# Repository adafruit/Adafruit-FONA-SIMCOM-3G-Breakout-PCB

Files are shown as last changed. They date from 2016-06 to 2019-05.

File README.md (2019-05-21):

## Adafruit FONA SIMCOM 3G Breakouts PCB
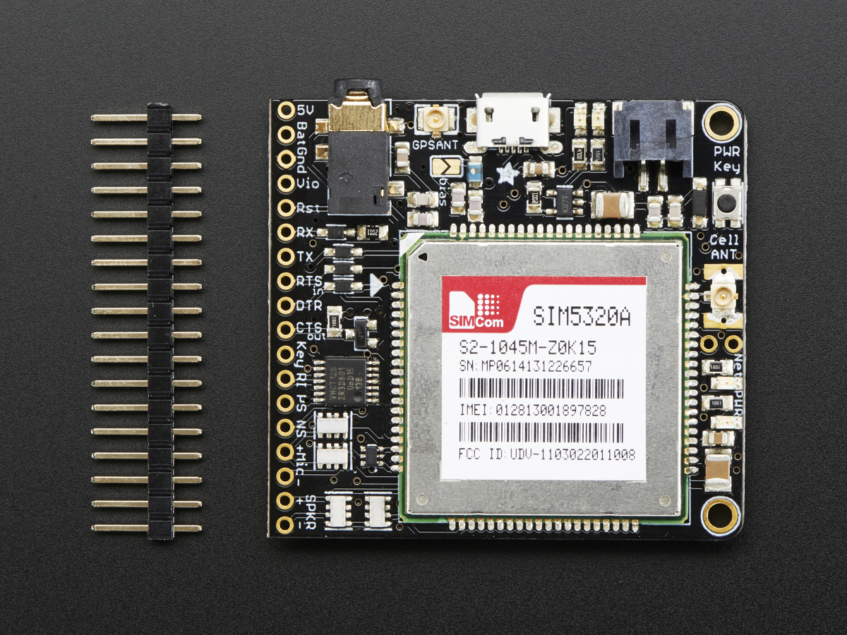
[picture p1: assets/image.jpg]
<a href="http://www.adafruit.com/products/3147"><br/>
Click here to purchase one from the Adafruit shop</a>

For those who want to take it to the next level we now have a 3G Cellular Modem breakout! The FONA 3G has better coverage, GSM backwards-compatibility and even sports a built-in GPS module for geolocation & asset tracking. This all-in-one cellular phone module with that lets you add location-tracking, voice, text, SMS and data to your project in a single breakout.

This module measure only 1.75"x1.6" but packs a surprising amount of technology into it's little frame. At the heart is a powerfull GSM cellular module (we use the latest SIM5320A) with integrated GPS.

For more details, see the various versions available:

  * https://www.adafruit.com/products/3147
  * https://www.adafruit.com/products/2687
  * https://www.adafruit.com/products/2691
  * https://www.adafruit.com/products/2696
  
PCB files for the Adafruit FONA SIMCOM 3G Breakout. The format is EagleCAD schematic and board layout

### License

Adafruit invests time and resources providing this open source design, please support Adafruit and open-source hardware by purchasing products from [Adafruit](https://www.adafruit.com)!

All text above must be included in any redistribution

Designed by Limor Fried/Ladyada for Adafruit Industries.
Creative Commons Attribution/Share-Alike, all text above must be included in any redistribution. 
See license.txt for additional information.

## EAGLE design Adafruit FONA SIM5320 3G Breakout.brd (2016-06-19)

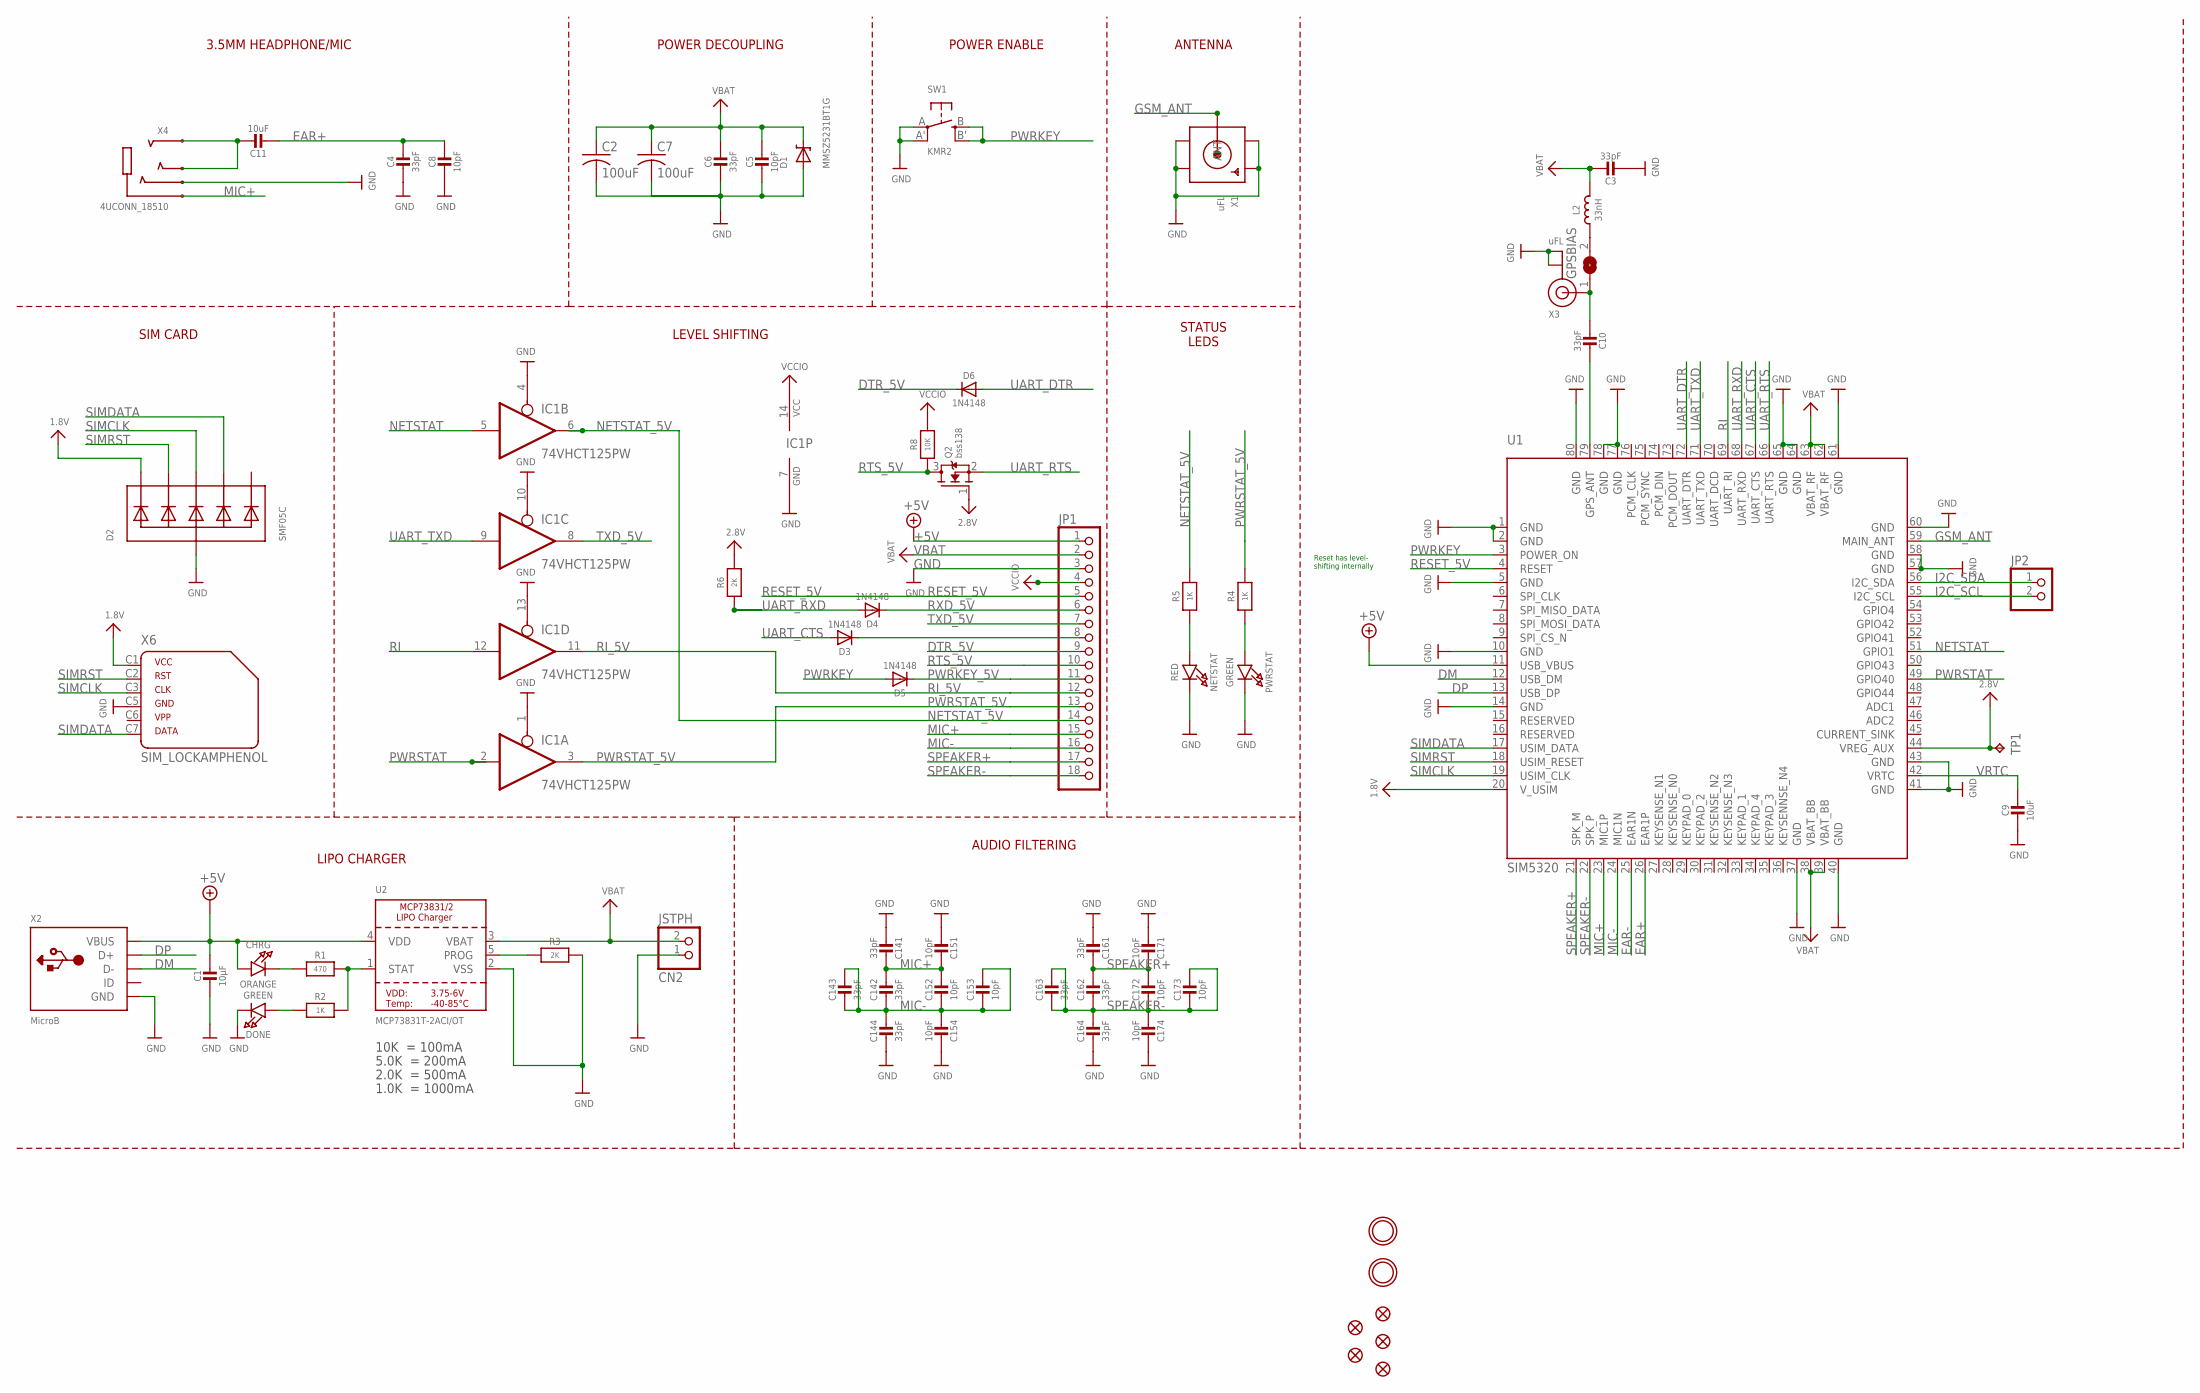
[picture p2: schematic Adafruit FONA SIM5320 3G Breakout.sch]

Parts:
C1: 10µF; 0805-NO
C2, C7: 100uF; C1210
C3, C4, C6, C10: 33pF; 0805-NO
C5, C8: 10pF; 0805-NO
C9, C11: 10uF; 0805-NO
C14, C16: 33pF; RESPACK_4X0603
C15, C17: 10pF; RESPACK_4X0603
CHRG: ORANGE; CHIPLED_0805_NOOUTLINE
CN2: JSTPH; JSTPH2
D1: MMSZ5231BT1G; SOD-123
D2: SMF05C; SOT363
D3, D4, D5, D6: 1N4148; SOD-323
DONE: GREEN; CHIPLED_0805_NOOUTLINE
FID1, FID2, FID3, FID4, FID5: FIDUCIAL""; FIDUCIAL_1MM
GPSBIAS: SOLDERJUMPER; SOLDERJUMPER_ARROW_NOPASTE
IC1: 74VHCT125PW; TSSOP14
JP1: HEADER-1X18; 1X18_ROUND70
JP2: HEADER-1X2ROUND; 1X02_ROUND
L2: 33nH; _0805MP
NETSTAT: RED; CHIPLED_0805_NOOUTLINE
PWRSTAT: GREEN; CHIPLED_0805_NOOUTLINE
Q2: bss138; SOT23-WIDE
R1: 470; 0805-NO
R2, R4, R5: 1K; 0805-NO
R3, R6: 2K; 0805-NO
R8: 10K; 0805-NO
SW1: KMR2; BTN_KMR2_4.6X2.8
TP1: TPTP11R; TP11R
U1: SIM5320
U2: MCP73831T-2ACI/OT; SOT23-5
U$33, U$34: MOUNTINGHOLE2.5; MOUNTINGHOLE_2.5_PLATED
X1: uFL; SMA_EDGELAUNCH_UFL
X2: MicroB; 4UCONN_20329
X3: uFL; U.FL
X4: 4UCONN_18510
X6: SIM_LOCKAMPHENOL; C707_10M006_512_2

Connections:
1.8V: D2.1 (C1), U1.20 (V_USIM), X6.C1 (1)
2.8V: Q2.1 (G), R6.2, TP1.TP, U1.44 (VREG_AUX)
+5V: C1.1, CHRG.A, JP1.1, U1.11 (USB_VBUS), U2.4 (VDD), X2.VBUS
CTS_5V: D3.C, JP1.8
DM: U1.12 (USB_DM), X2.D-
DP: U1.13 (USB_DP), X2.D+
DTR_5V: D6.C, JP1.9
EAR+: C4.1, C8.1, C11.2, U1.26 (EAR1P)
EAR-: U1.25 (EAR1N)
GND: C1.2, C2.2, C3.2, C4.2, C5.2, C6.2, C7.2, C8.2, C9.2, C14.5 (2), C14.8 (2), C15.4 (1), C15.8 (2), C16.5 (2), C16.8 (2), C17.4 (1), C17.8 (2), CN2.1, D1.A, D2.2 (A), DONE.C, IC1.1 (OE), IC1.4 (OE), IC1.7 (GND), IC1.10 (OE), IC1.13 (OE), JP1.3, NETSTAT.C, PWRSTAT.C, R3.2, SW1.A, SW1.A' (P1), U1.1 (GND), U1.2 (GND), U1.5 (GND), U1.10 (GND), U1.14 (GND), U1.37 (GND), U1.40 (GND), U1.41 (GND), U1.43 (GND), U1.57 (GND), U1.58 (GND), U1.60 (GND), U1.61 (GND), U1.64 (GND), U1.65 (GND), U1.77 (GND), U1.78 (GND), U1.80 (GND), U2.2 (VSS), X1.GND@1 (GND1), X1.GND@2 (GND2), X1.GND@3 (GND3), X1.GND@4 (GND4), X2.BASE@1 (GND), X2.BASE@2 (GND), X2.GND, X2.SPRT@1 (GND), X2.SPRT@2 (GND), X2.SPRT@3 (GND), X2.SPRT@4 (GND), X3.1 (GND), X3.2 (GND), X4.4-INNER_SLEEVE (RING1), X6.C5 (4)
GSM_ANT: U1.59 (MAIN_ANT), X1.P (ANT)
HP+: C11.1, X4.2-TIP (RING3), X4.3-OUTER_SLEEVE (RING2)
I2C_SCL: JP2.2, U1.55 (I2C_SCL)
I2C_SDA: JP2.1, U1.56 (I2C_SDA)
MIC+: C14.1, C14.2 (1), C15.1, C15.2 (1), JP1.15, U1.23 (MIC1P), X4.1-GND (TIP)
MIC-: C14.3 (1), C14.4 (1), C14.6 (2), C14.7 (2), C15.3 (1), C15.5 (2), C15.6 (2), C15.7 (2), JP1.16, U1.24 (MIC1N)
unnamed: CHRG.C, R1.1
unnamed: R1.2, R2.2, U2.1 (STAT)
unnamed: C10.2, GPSBIAS.1, X3.3 (SIGNAL)
unnamed: PWRSTAT.A, R4.1
unnamed: R3.1, U2.5 (PROG)
unnamed: DONE.A, R2.1
unnamed: C10.1, U1.79 (GPS_ANT)
unnamed: NETSTAT.A, R5.1
unnamed: GPSBIAS.2, L2.1
NETSTAT: IC1.5 (I), U1.51 (GPIO1)
NETSTAT_5V: IC1.6 (O), JP1.14, R5.2
PWRKEY: D5.A, SW1.B (S), SW1.B' (S1), U1.3 (POWER_ON)
PWRKEY_5V: D5.C, JP1.11
PWRSTAT: IC1.2 (I), U1.49 (GPIO40)
PWRSTAT_5V: IC1.3 (O), JP1.13, R4.2
RESET_5V: JP1.5, U1.4 (RESET)
RI: IC1.12 (I), U1.69 (UART_RI)
RI_5V: IC1.11 (O), JP1.12
RTS_5V: JP1.10, Q2.3 (D), R8.1
RXD_5V: D4.C, JP1.6
SIMCLK: D2.4 (C3), U1.19 (USIM_CLK), X6.C3 (3)
SIMDATA: D2.5 (C4), U1.17 (USIM_DATA), X6.C7 (6)
SIMRST: D2.3 (C2), U1.18 (USIM_RESET), X6.C2 (2)
SPEAKER+: C16.1, C16.2 (1), C17.1, C17.2 (1), JP1.17, U1.21 (SPK_M)
SPEAKER-: C16.3 (1), C16.4 (1), C16.6 (2), C16.7 (2), C17.3 (1), C17.5 (2), C17.6 (2), C17.7 (2), JP1.18, U1.22 (SPK_P)
TXD_5V: IC1.8 (O), JP1.7
UART_CTS: D3.A, U1.67 (UART_CTS)
UART_DTR: D6.A, U1.72 (UART_DTR)
UART_RTS: Q2.2 (S), U1.66 (UART_RTS)
UART_RXD: D4.A, R6.1, U1.68 (UART_RXD)
UART_TXD: IC1.9 (I), U1.71 (UART_TXD)
VBAT: C2.1, C3.1, C5.1, C6.1, C7.1, CN2.2, D1.C, JP1.2, L2.2, U1.38 (VBAT_BB), U1.39 (VBAT_BB), U1.62 (VBAT_RF), U1.63 (VBAT_RF), U2.3 (VBAT)
VCCIO: IC1.14 (VCC), JP1.4, R8.2
VRTC: C9.1, U1.42 (VRTC)

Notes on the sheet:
10K = 100mA
5.0K = 200mA
2.0K = 500mA
1.0K = 1000mA
ANTENNA
POWER DECOUPLING
3.5MM HEADPHONE/MIC
SIM CARD
LEVEL SHIFTING
LIPO CHARGER
AUDIO FILTERING
STATUS LEDS
POWER ENABLE
Reset has level- shifting internally

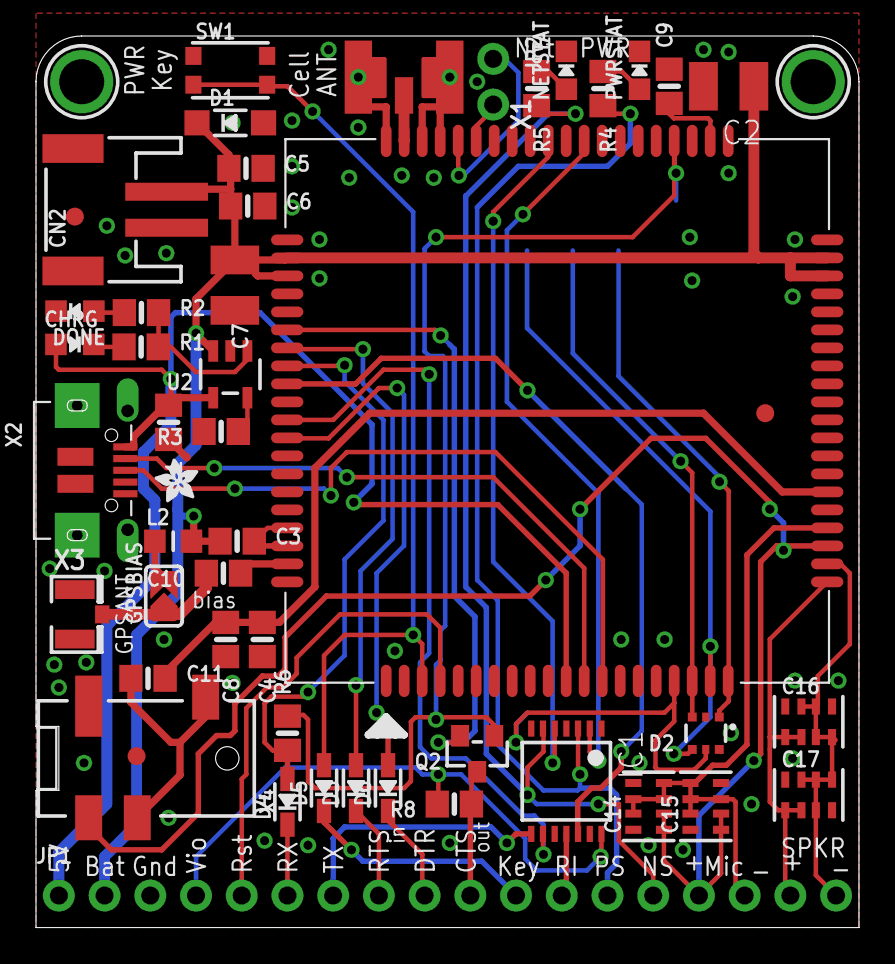
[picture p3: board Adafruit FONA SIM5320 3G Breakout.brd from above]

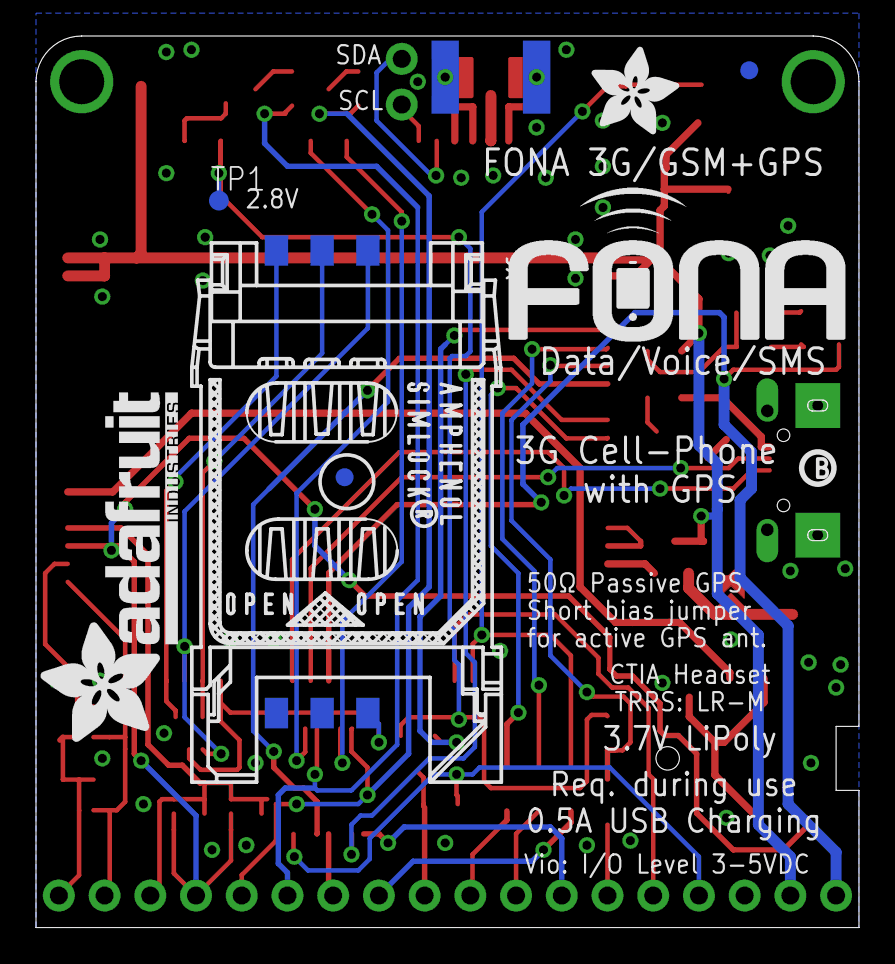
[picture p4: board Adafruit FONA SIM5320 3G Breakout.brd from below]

Board: 2 copper layers, 45.7 x 49.5 mm, 60 parts (8 on the bottom side), 49 nets.

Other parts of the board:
U$21: ADAFRUIT_2.5MM
U$25: PCBFEAT-REV-040
U$26: FONA_LOGO
U$36: ADAFRUIT_5MM
U$42: ADAFRUIT_TEXT_20MM

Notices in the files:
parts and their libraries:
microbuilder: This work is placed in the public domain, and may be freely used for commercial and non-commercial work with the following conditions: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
